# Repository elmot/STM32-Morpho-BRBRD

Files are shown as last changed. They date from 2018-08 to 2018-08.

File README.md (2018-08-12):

# STM32-Morpho-BRBRD

Prototyping shield for any STM32 Nucleo64 board.
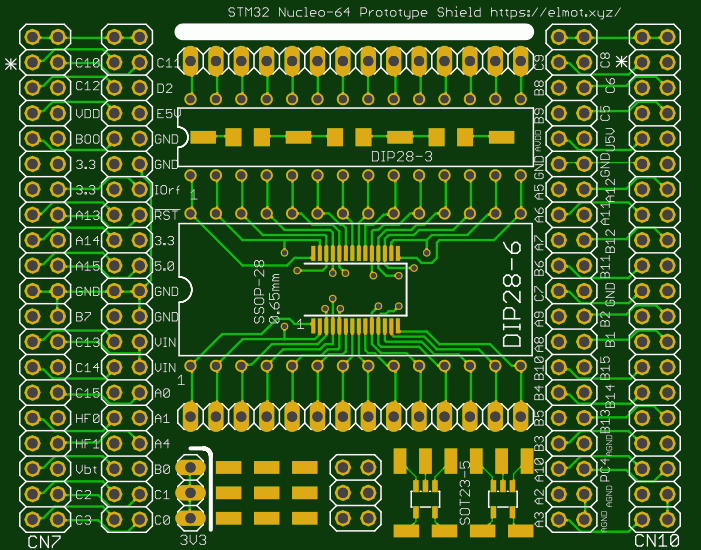
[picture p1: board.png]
Shield Outline


### Features:

* 55x70 mm
* All MCU pins solderable
* Wide DIL-28 footprint
* Narrow DIL-28 footprint
* (T)SSOP-28 (pitch 0.65mm) footprint (bottom)
* SOP-28 (pitch 1.27mm) footprint (top)
* Four SOT23-5 footprints (two per side)
* Six 1206 footprints in two chains (one chain per side)
* Free pads and pins for custom soldering

### NOTE

Original STM Morpho form-factor contains 2 * 19 connectrors. This shield uses 2 * 20 which are easier to buy. Be careful during soldering and connecting the shield to the Nucleo board.

### Status

12-Aug-18: First batch of PCBs submitted to PCB manufacturer

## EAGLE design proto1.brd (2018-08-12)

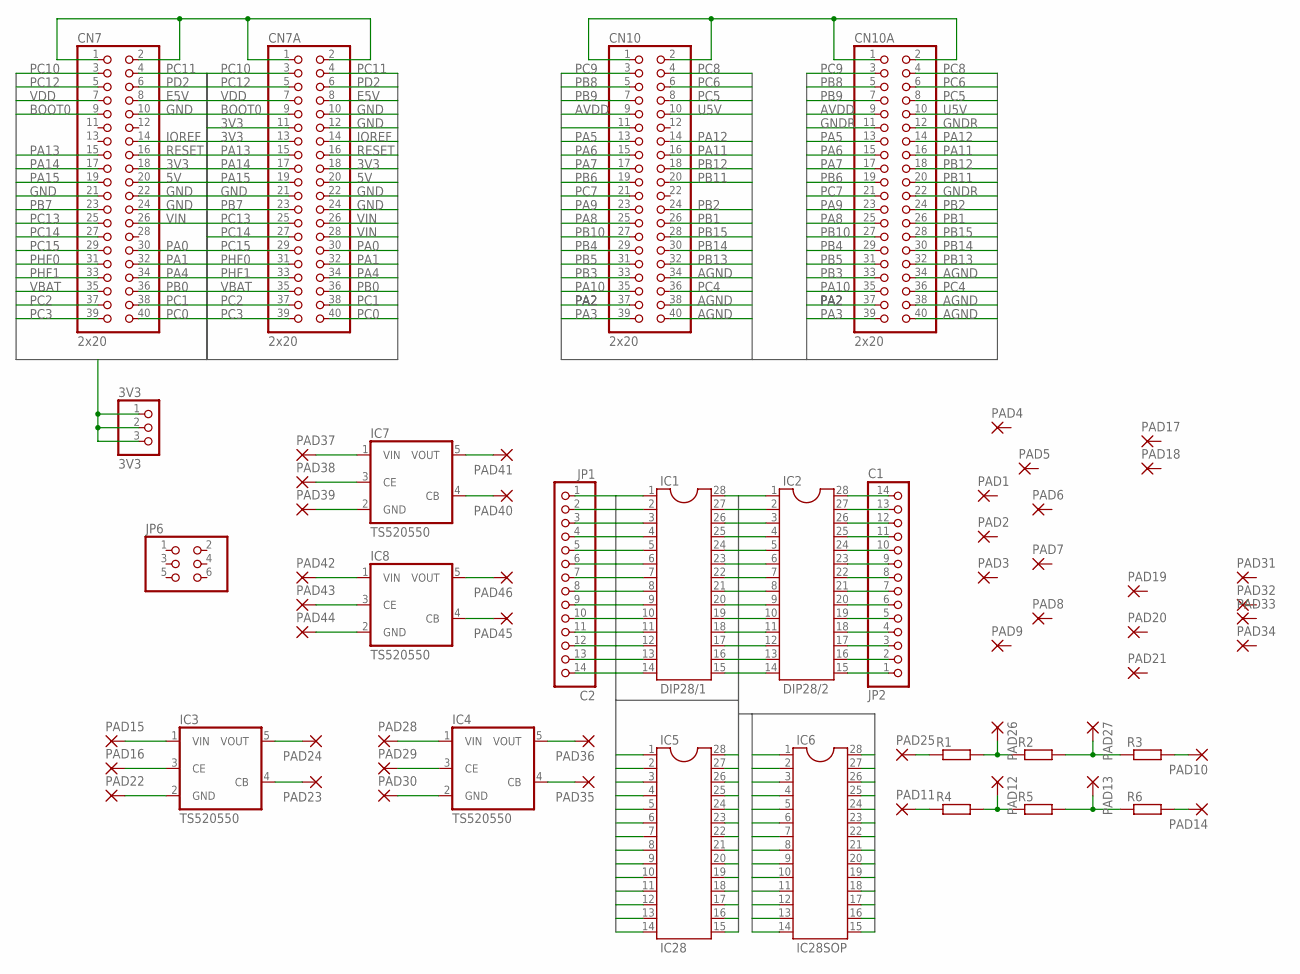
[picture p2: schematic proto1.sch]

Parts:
3V3: 3V3; 1X03
CN7, CN7A, CN10, CN10A: 2x20; 2X20
IC1: DIP28/1; DIL28-6
IC2: DIP28/2; DIL28-3
IC3, IC4, IC7, IC8: TS520550; SOT25
IC5: IC28; SSOP28
IC6: IC28SOP; SOP28
JP1: C2; 1X14
JP2: C1; 1X14
JP6: PINHD-2X3; 2X03
PAD1, PAD2, PAD3, PAD4, PAD5, PAD6, PAD7, PAD8, PAD9, PAD10, PAD11, PAD12, PAD13, PAD14, PAD15, PAD16, PAD17, PAD18, PAD19, PAD20, PAD21, PAD22, PAD23, PAD24, PAD25, PAD26, PAD27, PAD28, PAD29, PAD30, PAD31, PAD32, PAD33, PAD34, PAD35, PAD36, PAD37, PAD38, PAD39, PAD40, PAD41, PAD42, PAD43, PAD44, PAD45, PAD46: SMD2; SMD1,27-2,54
R1, R2, R3, R4, R5, R6: R-EU_R1206; R1206

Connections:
3V3: 3V3.1, 3V3.2, 3V3.3, CN7.18, CN7A.11, CN7A.13, CN7A.18
5V: CN7.20, CN7A.20
AGND: CN10.34, CN10.38, CN10.40, CN10A.34, CN10A.38, CN10A.40
AVDD: CN10.9, CN10A.9
BOOT0: CN7.9, CN7A.9
E5V: CN7.8, CN7A.8
GND: CN7.10, CN7.21, CN7.22, CN7.24, CN7A.10, CN7A.12, CN7A.21, CN7A.22, CN7A.24
GNDR: CN10.11, CN10A.11, CN10A.12, CN10A.22
IC1: IC1.1, IC5.1, IC6.28, JP1.1
IC2: IC1.2, IC5.2, IC6.27, JP1.2
IC3: IC1.3, IC5.3, IC6.26, JP1.3
IC4: IC1.4, IC5.4, IC6.25, JP1.4
IC5: IC1.5, IC5.5, IC6.24, JP1.5
IC6: IC1.6, IC5.6, IC6.23, JP1.6
IC7: IC1.7, IC5.7, IC6.22, JP1.7
IC8: IC1.8, IC5.8, IC6.21, JP1.8
IC9: IC1.9, IC5.9, IC6.20, JP1.9
IC10: IC1.10, IC5.10, IC6.19, JP1.10
IC11: IC1.11, IC5.11, IC6.18, JP1.11
IC12: IC1.12, IC5.12, IC6.17, JP1.12
IC13: IC1.13, IC5.13, IC6.16, JP1.13
IC14: IC1.14, IC5.14, IC6.15, JP1.14
IC15: IC1.15, IC2.14, IC5.15, IC6.14
IC16: IC1.16, IC2.13, IC5.16, IC6.13
IC17: IC1.17, IC2.12, IC5.17, IC6.12
IC18: IC1.18, IC2.11, IC5.18, IC6.11
IC19: IC1.19, IC2.10, IC5.19, IC6.10
IC20: IC1.20, IC2.9, IC5.20, IC6.9
IC21: IC1.21, IC2.8, IC5.21, IC6.8
IC22: IC1.22, IC2.7, IC5.22, IC6.7
IC23: IC1.23, IC2.6, IC5.23, IC6.6
IC24: IC1.24, IC2.5, IC5.24, IC6.5
IC25: IC1.25, IC2.4, IC5.25, IC6.4
IC26: IC1.26, IC2.3, IC5.26, IC6.3
IC27: IC1.27, IC2.2, IC5.27, IC6.2
IC28: IC1.28, IC2.1, IC5.28, IC6.1
IOREF: CN7.14, CN7A.14
unnamed: CN10.1, CN10.2, CN10A.1, CN10A.2
unnamed: CN7.1, CN7.2, CN7A.1, CN7A.2
unnamed: IC2.28, JP2.14
unnamed: IC2.27, JP2.13
unnamed: IC2.26, JP2.12
unnamed: IC2.25, JP2.11
unnamed: IC2.24, JP2.10
unnamed: IC2.23, JP2.9
unnamed: IC2.22, JP2.8
unnamed: IC2.21, JP2.7
unnamed: IC2.20, JP2.6
unnamed: IC2.19, JP2.5
unnamed: IC2.18, JP2.4
unnamed: IC2.17, JP2.3
unnamed: IC2.16, JP2.2
unnamed: IC2.15, JP2.1
unnamed: PAD25.1, R1.1
unnamed: PAD26.1, R1.2, R2.1
unnamed: PAD27.1, R2.2, R3.1
unnamed: PAD10.1, R3.2
unnamed: PAD11.1, R4.1
unnamed: PAD12.1, R4.2, R5.1
unnamed: PAD13.1, R5.2, R6.1
unnamed: PAD14.1, R6.2
unnamed: IC3.1 (VIN), PAD15.1
unnamed: IC3.3 (CE), PAD16.1
unnamed: IC3.2 (GND), PAD22.1
unnamed: IC3.4 (CB), PAD23.1
unnamed: IC3.5 (VOUT), PAD24.1
unnamed: IC4.1 (VIN), PAD28.1
unnamed: IC4.3 (CE), PAD29.1
unnamed: IC4.2 (GND), PAD30.1
unnamed: IC4.4 (CB), PAD35.1
unnamed: IC4.5 (VOUT), PAD36.1
unnamed: IC7.1 (VIN), PAD37.1
unnamed: IC7.3 (CE), PAD38.1
unnamed: IC7.2 (GND), PAD39.1
unnamed: IC7.4 (CB), PAD40.1
unnamed: IC7.5 (VOUT), PAD41.1
unnamed: IC8.1 (VIN), PAD42.1
unnamed: IC8.3 (CE), PAD43.1
unnamed: IC8.2 (GND), PAD44.1
unnamed: IC8.4 (CB), PAD45.1
unnamed: IC8.5 (VOUT), PAD46.1
PA0: CN7.30, CN7A.30
PA1: CN7.32, CN7A.32
PA2: CN10.37, CN10A.37
PA3: CN10.39, CN10A.39
PA4: CN7.34, CN7A.34
PA5: CN10.13, CN10A.13
PA6: CN10.15, CN10A.15
PA7: CN10.17, CN10A.17
PA8: CN10.25, CN10A.25
PA9: CN10.23, CN10A.23
PA10: CN10.35, CN10A.35
PA11: CN10.16, CN10A.16
PA12: CN10.14, CN10A.14
PA13: CN7.15, CN7A.15
PA14: CN7.17, CN7A.17
PA15: CN7.19, CN7A.19
PB0: CN7.36, CN7A.36
PB1: CN10.26, CN10A.26
PB2: CN10.24, CN10A.24
PB3: CN10.33, CN10A.33
PB4: CN10.29, CN10A.29
PB5: CN10.31, CN10A.31
PB6: CN10.19, CN10A.19
PB7: CN7.23, CN7A.23
PB8: CN10.5, CN10A.5
PB9: CN10.7, CN10A.7
PB10: CN10.27, CN10A.27
PB11: CN10.20, CN10A.20
PB12: CN10.18, CN10A.18
PB13: CN10.32, CN10A.32
PB14: CN10.30, CN10A.30
PB15: CN10.28, CN10A.28
PC0: CN7.40, CN7A.40
PC1: CN7.38, CN7A.38
PC2: CN7.37, CN7A.37
PC3: CN7.39, CN7A.39
PC4: CN10.36, CN10A.36
PC5: CN10.8, CN10A.8
PC6: CN10.6, CN10A.6
PC7: CN10.21, CN10A.21
PC8: CN10.4, CN10A.4
PC9: CN10.3, CN10A.3
PC10: CN7.3, CN7A.3
PC11: CN7.4, CN7A.4
PC12: CN7.5, CN7A.5
PC13: CN7.25, CN7A.25
PC14: CN7.27, CN7A.27
PC15: CN7.29, CN7A.29
PD2: CN7.6, CN7A.6
PHF0: CN7.31, CN7A.31
PHF1: CN7.33, CN7A.33
RESET: CN7.16, CN7A.16
U5V: CN10.10, CN10A.10
VBAT: CN7.35, CN7A.35
VDD: CN7.7, CN7A.7
VIN: CN7.26, CN7A.26, CN7A.28

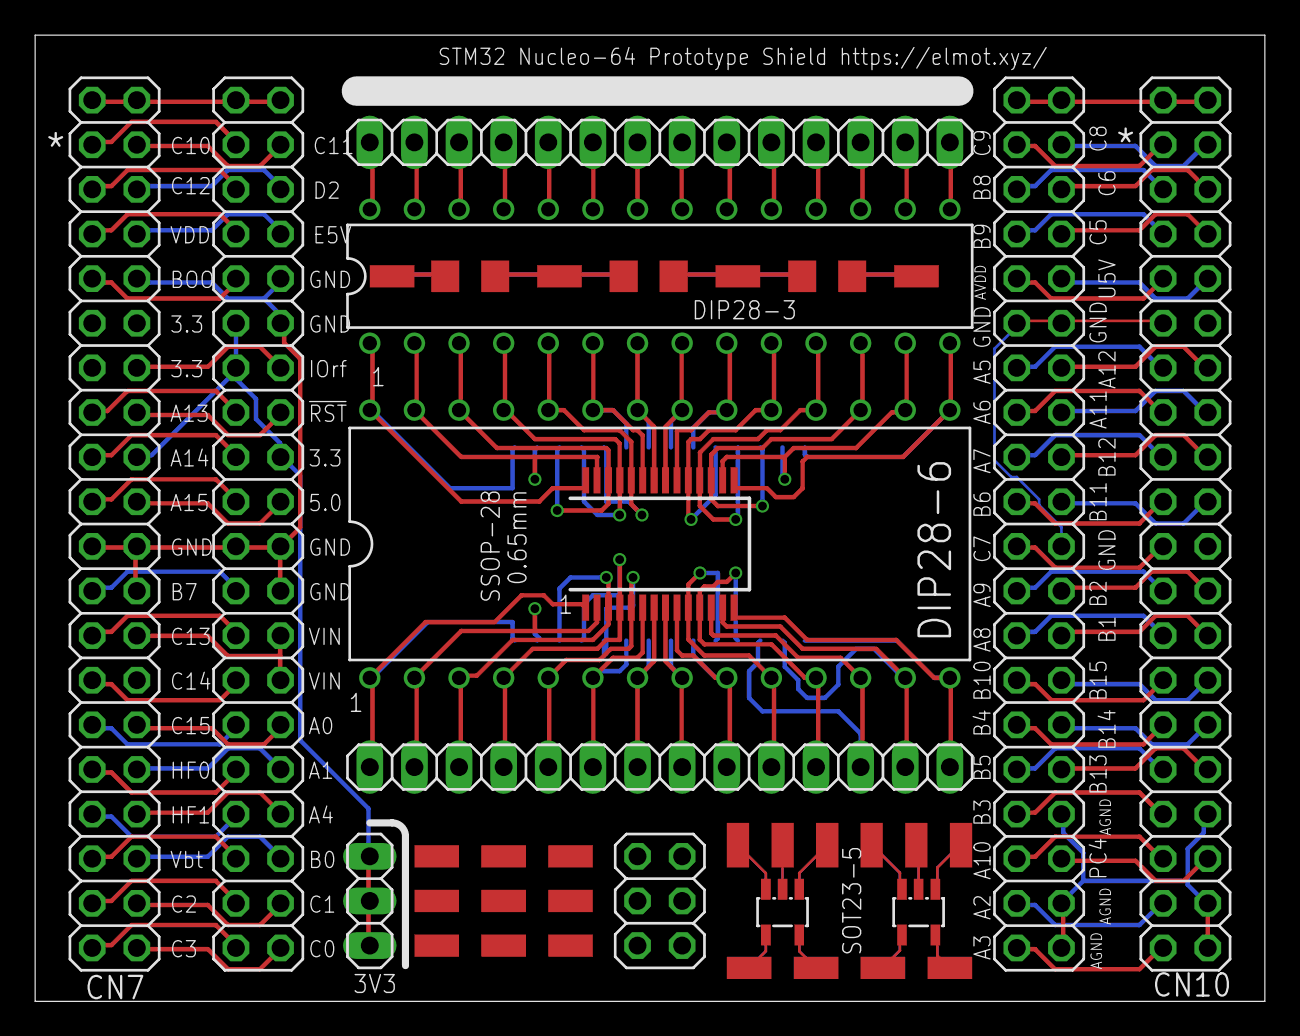
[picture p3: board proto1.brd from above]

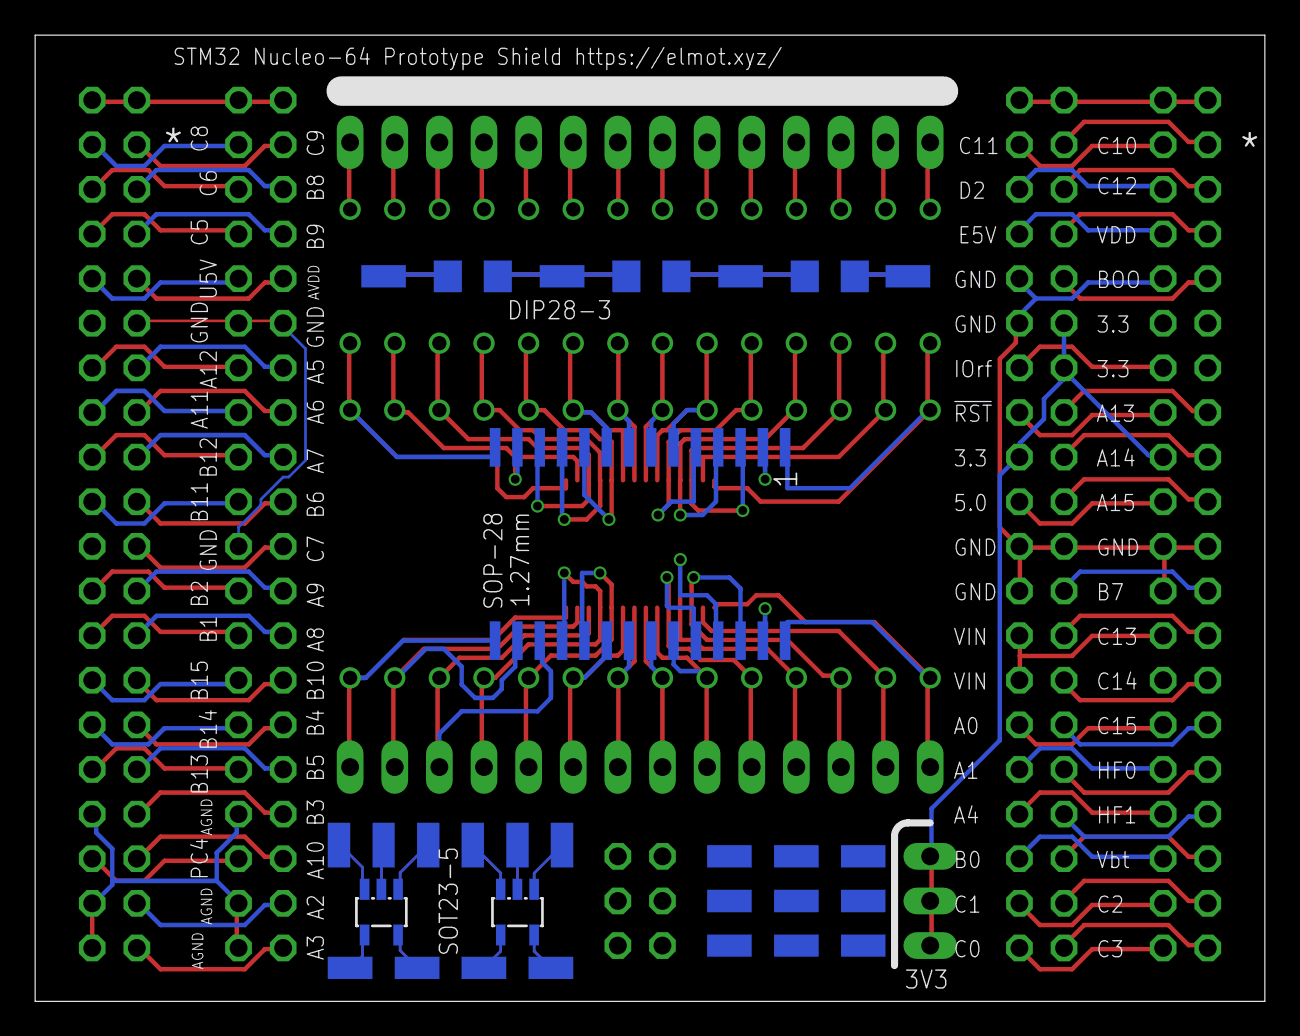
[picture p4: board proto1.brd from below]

Board: 2 copper layers, 70.0 x 55.0 mm, 68 parts (29 on the bottom side), 137 nets.
